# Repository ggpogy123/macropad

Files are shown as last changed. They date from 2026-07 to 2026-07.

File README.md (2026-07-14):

# Custom Macropad
A custom-designed macropad board using Raspberry Pi Pico 2, dual rotary encoders, three switches and a dedicated 1.8 inch SPI display.

## Visuals





## Hardware Specifications
* **Microcontroller:** Raspberry Pi Pico 2
* **Display:** 1.8-inch TFT LCD Module (SPI Interface)
* **Inputs:** 3x Buildcon Blue Mechanical Keyswitches & 2x Flyrobo EC11 15mm Rotary Encoders
* **Knobs & Keycaps:** 2x Black Aluminum Alloy 19x19mm Screw-Type Knobs & Trendivibe PBT MA Profile Ball Shape Keycaps
* **PCB Specs:** 2-layer FR4, 124.0 x 104.0 mm, 1.6mm thickness

## Key Design Features
* **Using Berg strip:** Things are fully socketed using Berg strips, allowing for easy swapping, testing and safety during soldering.
* **Ground Plane:** A dedicated copper pour layer has been used across the layout to connect all GND points.

## Pin layout

### Display (J1)

| Pin Name | Connection Type | Pico pin | Working |
| :--- | :--- | :--- | :--- |
| 3V3 | Power | 3V3 | Power |
| GND | Ground | GND | Ground |
| DISP_CS | SPI Chip Select | GPIO 9 | Chip Select |
| DISP_RESET | Shared Reset | GPIO 13 | Hardware Reset |
| DISP_DC | Digital Output | GPIO 12 | Data/Command |
| SPI_MOSI | SPI Data | GPIO 15 | Master Out Slave In |
| SPI_SCK | SPI Clock | GPIO 14 | Serial Clock |
| 3V3 | Power | 3V3 | Backlight |

### Switches

| Pin Name | Connection Type | Pico pin | Working |
| :--- | :--- | :--- | :--- |
| KEY_BACK | Digital Input | GPIO 0 | SW1  |
| KEY_PAUSE | Digital Input | GPIO 1 | SW2  |
| KEY_NEXT | Digital Input | GPIO 2 | SW3  |

### Encoders

| Pin Name | Connection Type | Pico pin | Working |
| :--- | :--- | :--- | :--- |
| ENC1_A | Digital Input | GPIO 3 | Rotary 1 Phase A |
| ENC1_B | Digital Input | GPIO 4 | Rotary 1 Phase B |
| ENC1_SW | Digital Input | GPIO 5 | Rotary 1 Click |
| ENC2_A | Digital Input | GPIO 6 | Rotary 2 Phase A |
| ENC2_B | Digital Input | GPIO 7 | Rotary 2 Phase B |
| ENC2_SW | Digital Input | GPIO 8 | Rotary 2 Click |

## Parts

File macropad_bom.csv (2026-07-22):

Macropad Bill of Materials
Item # | Manufacturer | Item name | Quantity | Price of each item | Shipping Cost | Total Price (inr) | Buying from | Links
1 |  | 1.8 inch TFT LCD Module | 1 | 279 | 49 | 328 | Robocraze.com | https://robu.in/product/62060/
2 |  | Raspberry Pi Pico 2 with Header | 1 | 619 | 0 | 619 | Robu.in | https://robu.in/product/raspberry-pi-pico-2-with-header/
3 | Buildcon | 20 Pcs Mechanical Keyboard Switches, Blue Switch Mechanical Keyboard, Gaming Keyboard Switches, MX Mechanical Blue Switches, Universal Keyboard Switches for Custom Mechanical Keyboards | 1 | 399 | 0 | 399 | Amazon | https://www.amazon.in/Buildcon-Mechanical-Keyboard-Universal-Keyboards/dp/B0GCCQLQBV
4 | Flyrobo | (2 pc) Flyrobo EC11 Rotary Encoder Half Shaft Handle Potentiometer | 15mm | 1 | 282 | 0 | 282 | Amazon | https://www.amazon.in/Flyrobo-Rotary-Encoder-Handle-Potentiometer/dp/B0H6CT1NBC
5 | URJIX | PBT Keycaps/MA Profile Ball Shape for All Cherrymx Mechanical Keyboard Black | 1 | 644 | 0 | 644 | Amazon | https://www.amazon.in/URJIXTM-Keycaps-Cherrymx-Mechanical-Keyboard/dp/B0H7JGSRCX
6 |  | Black Aluminum Alloy Potentiometer Control Knob Volume Audio Electric Guitar Bass Screw Type 19 x 19mm KNOB-06-19-BKDC (2Pcs) | 1 | 299 | 0 | 299 | Amazon | https://www.amazon.in/Aluminum-Potentiometer-Control-Electric-KNOB-06-19-BKDC/dp/B0GTPZBCBJ
7 |  | 40x1 Female Berg Strip | 3 | 9 | Combined with LCD | 27 | Robocraze.com | https://robocraze.com/products/40x1-female-berg-strip
8 | lioncircuits | PCB | 5 | 451.2 | 0 | 2662 | lioncircuits.com | -
 |  | Total | 14 | 2982.2 | 49 | 5260

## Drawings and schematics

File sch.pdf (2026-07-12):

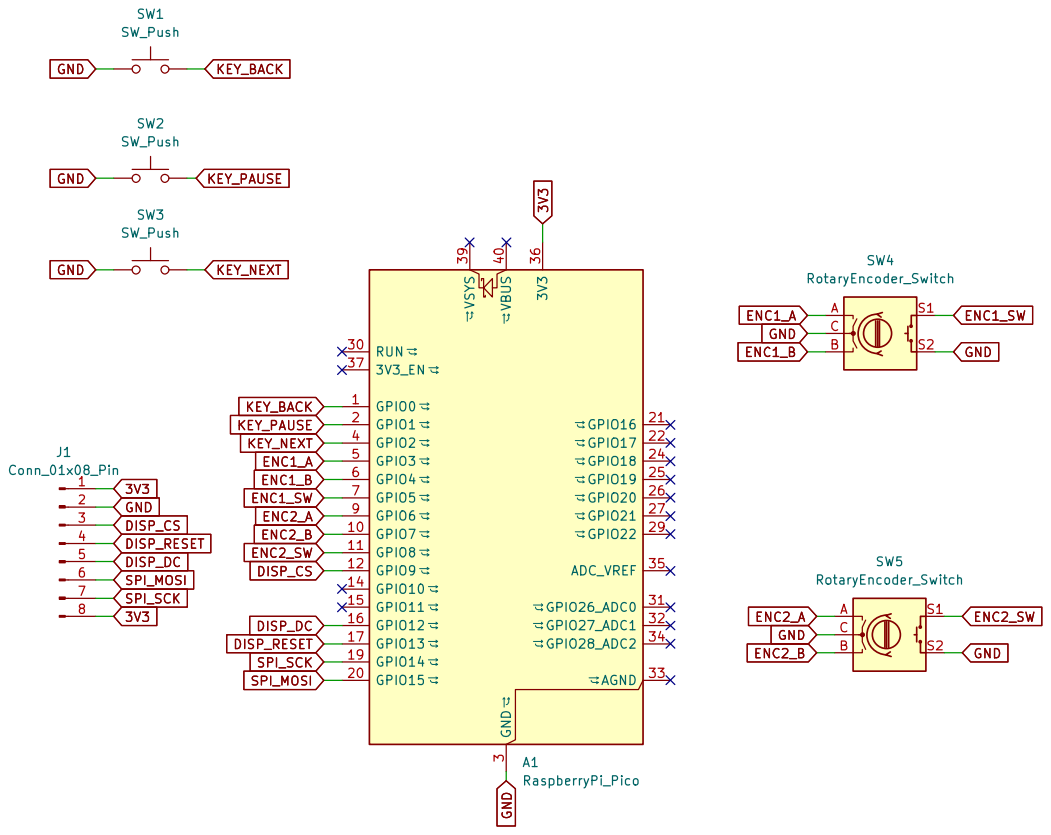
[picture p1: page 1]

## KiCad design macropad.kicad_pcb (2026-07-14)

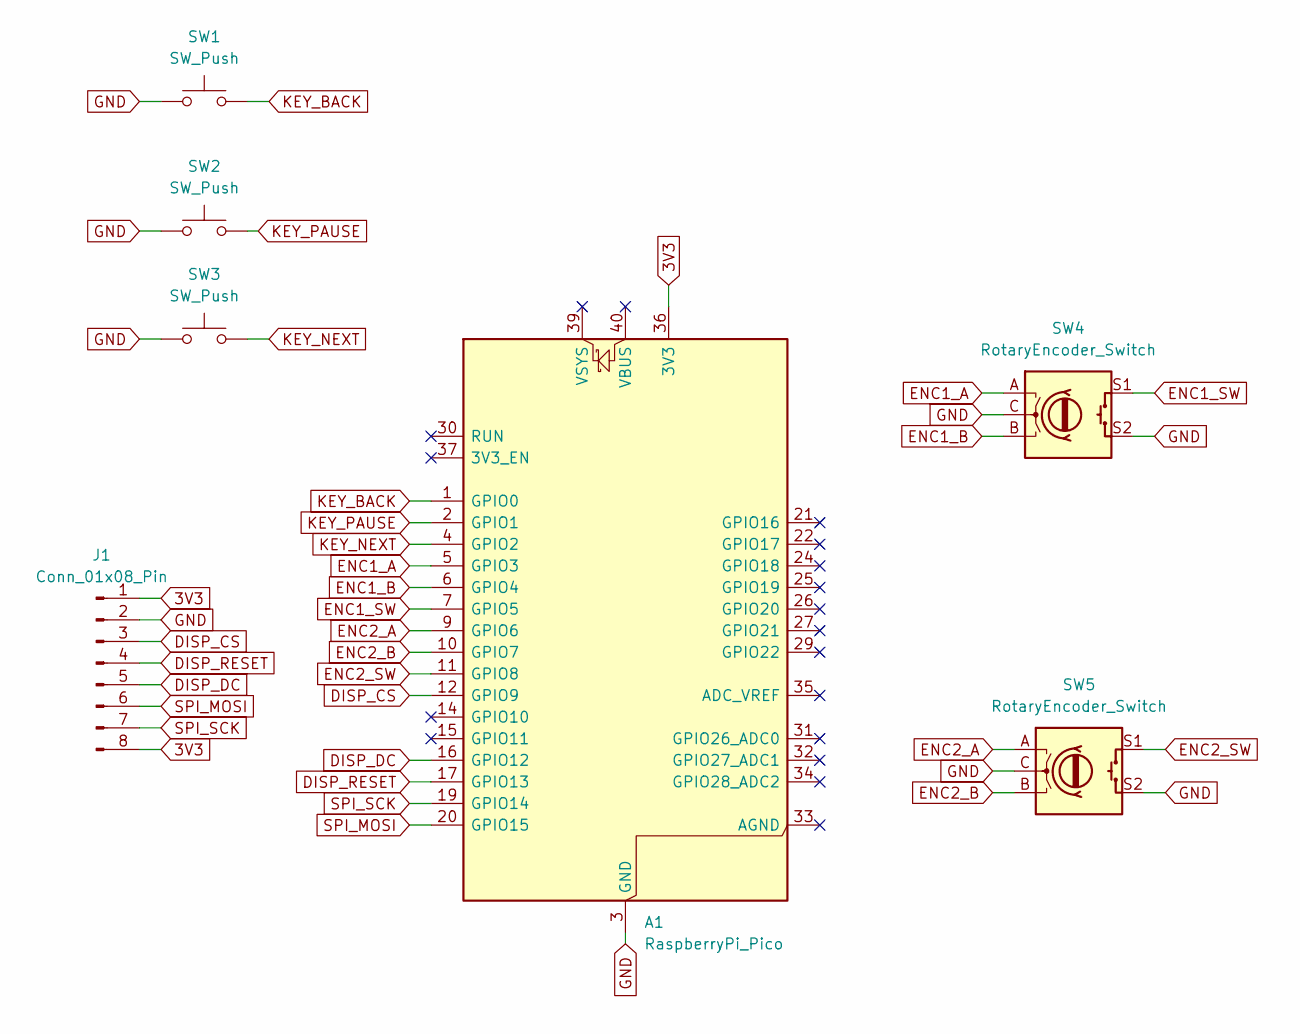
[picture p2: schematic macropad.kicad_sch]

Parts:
A1: RaspberryPi_Pico; RaspberryPi_Pico_Common_THT
J1: Conn_01x08_Pin; PinSocket_1x08_P2.54mm_Vertical
SW1, SW2, SW3: SW_Push; SW_Cherry_MX_1.00u_Plate
SW4, SW5: RotaryEncoder_Switch; RotaryEncoder_Alps_EC11E-Switch_Vertical_H20mm

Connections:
3V3: A1.36 (3V3), J1.1, J1.8
DISP_CS: A1.12 (GPIO9), J1.3
DISP_DC: A1.16 (GPIO12), J1.5
DISP_RESET: A1.17 (GPIO13), J1.4
ENC1_A: A1.5 (GPIO3), SW4.A
ENC1_B: A1.6 (GPIO4), SW4.B
ENC1_SW: A1.7 (GPIO5), SW4.S1
ENC2_A: A1.9 (GPIO6), SW5.A
ENC2_B: A1.10 (GPIO7), SW5.B
ENC2_SW: A1.11 (GPIO8), SW5.S1
GND: A1.3 (GND), A1.8 (GND), A1.13 (GND), A1.18 (GND), A1.23 (GND), A1.28 (GND), A1.38 (GND), J1.2, SW1.1, SW2.1, SW3.1, SW4.C, SW4.S2, SW5.C, SW5.S2
KEY_BACK: A1.1 (GPIO0), SW1.2
KEY_NEXT: A1.4 (GPIO2), SW3.2
KEY_PAUSE: A1.2 (GPIO1), SW2.2
SPI_MOSI: A1.20 (GPIO15), J1.6
SPI_SCK: A1.19 (GPIO14), J1.7

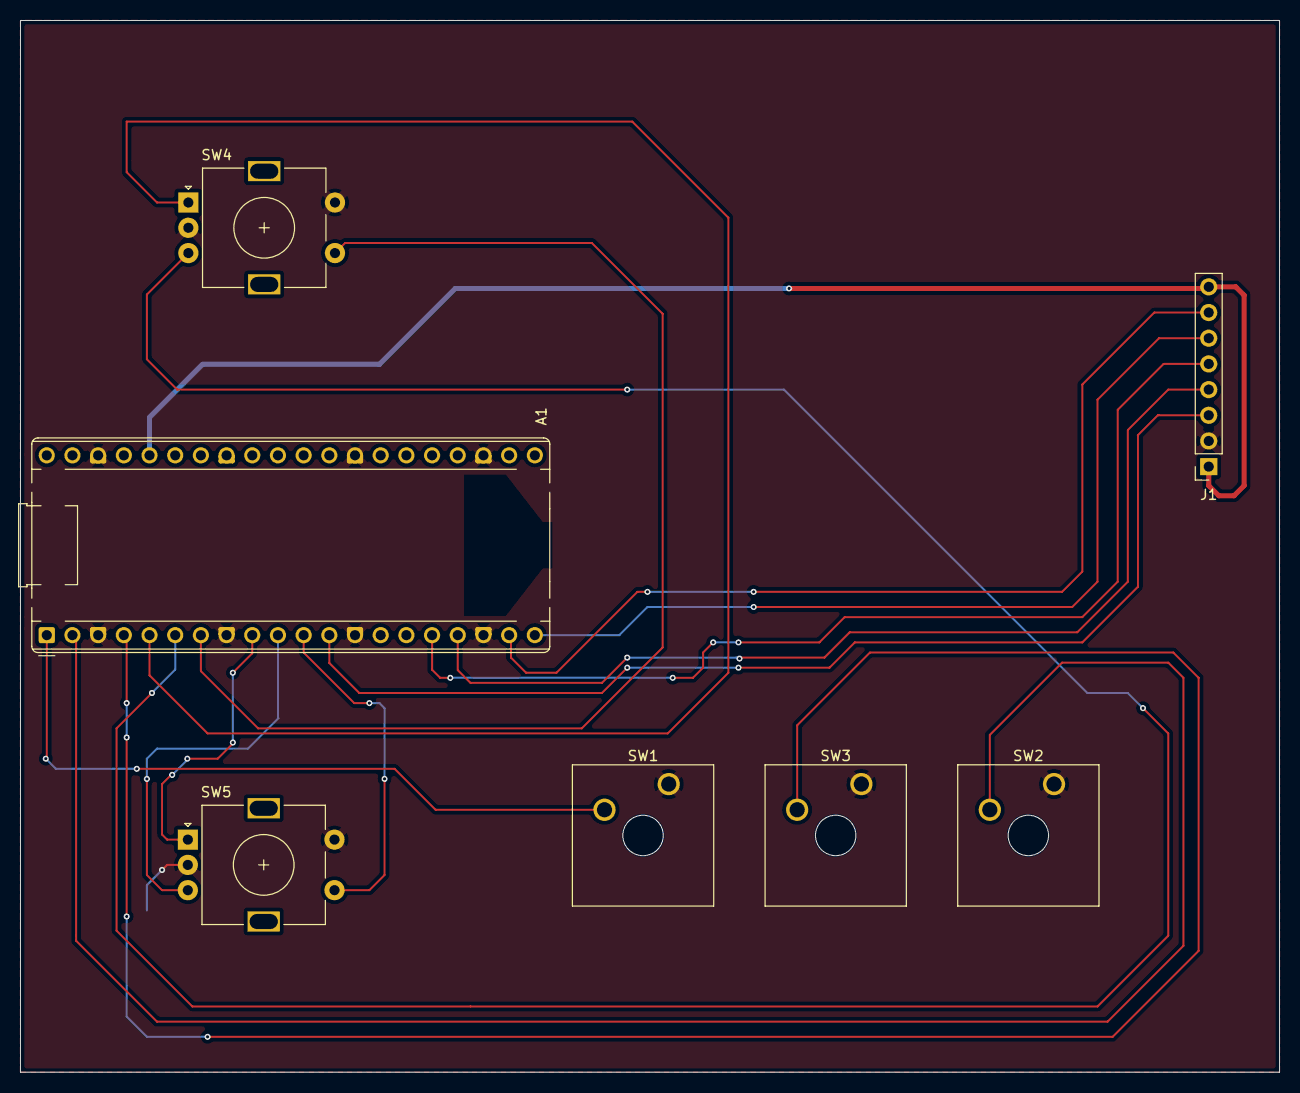
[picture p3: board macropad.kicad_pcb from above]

Board: 2 copper layers, 124.5 x 104.0 mm, 7 parts (0 on the bottom side), 16 nets.
